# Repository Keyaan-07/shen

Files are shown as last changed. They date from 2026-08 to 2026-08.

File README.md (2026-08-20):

# SHEN
Shen is a low-cost pico-sized RP2350A development board along with the raspberry pi RM2, in a small 21mmx51mm form factor, with USB-C support. It is a 4 layer stackup with 1.0mm thickness.  

Check out the PCB online on [KiCanvas](https://kicanvas.org/?repo=https%3A%2F%2Fgithub.com%2FKeyaan-07%2Fshen%2Ftree%2Fmain%2Fhardware)

## Features
- WiFi and Bluetooth support
- dual-core
- 4MiB Flash storage(expandable upto 16MiB)
- User-LED
- High efficiency sychronous buck converter
- USB Boot
- Curvy Traces

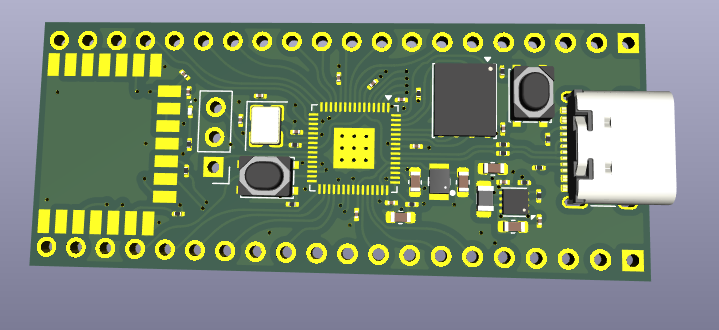
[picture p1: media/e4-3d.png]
3d render
  
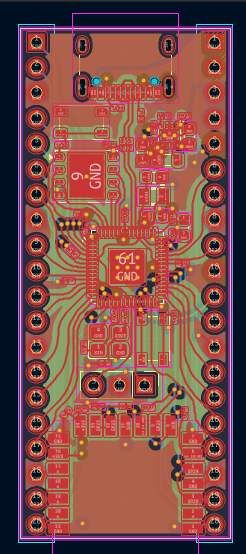
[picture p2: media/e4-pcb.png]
pcb

schematic

## BOM
Some parts(such as those in quantities of 50 and 100) are chosen because of the MOQ. 
|Designator |Function |Value |Footprint |Quantity|Price |Amount|Link |
|---|---|---|---|---|---|---|---|
|PCB |PCB | |21x51 |5+1 |2.1+3.07 |5.17  |https://jlcpcb.com/ |
|C1, C2, C4 |Capacitor |4.7u |603 |50 |0.0048 |0.24  |https://robu.in/product/tcc0603x5r475m160ct-cctc-smt-ceramic-capacitors-0603-x5r-475m4-7%c2%b5f%c2%b120-rated-voltage16v-thickness0-80mm-tape/ |
|C10, C11, C12, C13, C14, C18, C20, C5, C6, C7, C8, C9|Capacitor |100n |201 |100 |0.0011 |0.11  |https://robu.in/product/cl03a104ko3nnnc-samsang-16v-100nf-x5r-%c2%b110-0201-multilayer-ceramic-capacitors-mlcc-smd-smt-rohs/ |
|C15, C16 |Capacitor |22p |201 |50 |0.004 |0.2 |https://robu.in/product/grm0335c1h220ja01d-murata-cap-ceramic-22pf-50v-c0g-5-pad-smd-0201-125c-automotive-t-r/ |
|C17, C19 |Capacitor |10u |603 |4 |0.03 |0.12  |https://www.lcsc.com/product-detail/C7393892.html |
|D1 |LED |LED |402 |4 |0.01 |0.04  |https://www.lcsc.com/product-detail/C7496805.html |
|J4 |USB-C |USB_C_Receptacle_USB2.0_16P|USB_C_Receptacle_XKB_U262-16XN-4BVC11 |2 |0.06 |0.12  |https://www.lcsc.com/product-detail/C393939.html |
|L1 |Inductor |3.3u |IND-SMD_L2.0-W1.6_AOTA-B201610S3R3-101-T|2 |0.28 |0.56  |https://www.lcsc.com/product-detail/C42411119.html |
|L2 |Inductor |1u |805 |5 |0.13 |0.65  |https://robu.in/product/mlp2012h1r0mt0s1-tdk-1-1a-1uh-%c2%b120-120m%cf%89-0805-inductors-smd-rohs/ |
|R1, R2 |Resistor |27 |201 |50 |0.0038 |0.19  |https://robu.in/product/rc0201fr-0727rl-yageo-smd-chip-resistor-27-ohm-%C2%B1-1-50-mw-0201-0603-metric-thick-film-general-purpose/ |
|R9 |Resistor |63.4k |201 |100 |0.0011 |0.11  |https://robu.in/product/rc0201fr-0763k4l-yageo-50mw-thick-film-resistors-25v-%c2%b11-%c2%b1200ppm-%e2%84%83-63-4k%cf%89-0201-chip-resistor-surface-mount-rohs/ |
|R11 |Resistor |470 |201 |50 |0.0038 |0.19  |https://robu.in/product/0201wmj0471tee-uniohm-royal-ohm-50mw-thick-film-resistors-25v-%c2%b15-%c2%b1200ppm-%e2%84%83-470%cf%89-0201-chip-resistor-surface-mount-rohs/|
|R10, R12 |Resistor |10k |201 |50 |0.0038 |0.19  |https://robu.in/product/0201wmf1002tee-uniohm-royal-ohm-50mw-thick-film-resistors-25v-%c2%b11-%c2%b1200ppm-%e2%84%83-10k%cf%89-0201-chip-resistor-surface-mount-rohs/|
|R13, R14 |Resistor |5.1k |201 |50 |0.0038 |0.19  |https://robu.in/product/0201wmf5101tee-uniohm-royal-ohm-50mw-thick-film-resistors-25v%c2%b11%c2%b1200ppm-%e2%84%83-5-1k%cf%89-0201-chip-resistor-surface-mount-rohs/ |
|R3, R5, R6, R7, R8 |Resistor |1K |201 |50 |0.0038 |0.19  |https://robu.in/product/0201wmf1001tee-uniohm-royal-ohm-50mw-thick-film-resistors-25v%c2%b11%c2%b1200ppm-%e2%84%83-1k%cf%89-0201-chip-resistor-surface-mount-rohs/ |
|R4 |Resistor |33 |201 |50 |0.0038 |0.19  |https://robu.in/product/0201wmf330jtee-uniohm-royal-ohm-50mw-thick-film-resistors-25v%c2%b11%c2%b1200ppm-%e2%84%83-33%cf%89-0201-chip-resistor-surface-mount-rohs/ |
|SW1, SW2 |Switch |SW_Push |SW_SPST_PTS810 |5 |0.27 |1.35  |https://robu.in/product/pts810sjm250smtrlfs-ck-3-2mm-2-5mm-round-button-50ma-standing-paste-4-2mm-spst-160gf-16v-smd-tactile-switches-rohs/ |
|U1 |MCU |RP2350A |QFN-60-1EP_7x7mm_P0.4mm_EP3.4x3.4mm |3 |1.14 |3.42  |https://robu.in/product/raspberry-pi-rp2350a-microcontroller-ic/ |
|U2 |Flash Storage|W25Q32JVZP |WSON-8-1EP_6x5mm_P1.27mm_EP3.4x4.3mm |2 |0.96 |1.92  |https://robu.in/product/w25q32jwzpiq-tr-winbond-elec-32mbit-spi-133mhz-wson-8-ep5x6-nor-flash-rohs/ |
|U3 |RF module |RPI-RM2 |RPI_RM2 |2 |6.99 |13.98 |https://robu.in/product/raspberry-pi-radio-module-rmc20452t/ |
|U4 |Buck |TLV62084DSGx |WSON-8-1EP_2x2mm_P0.5mm_EP0.9x1.6mm |3 |0.31 |0.93  |https://robu.in/product/1-month-warranty-565/ |
|Y1 |Crystal |12MHz |Crystal_SMD_3225-4Pin_3.2x2.5mm |5 |0.19 |0.95  |https://robu.in/product/ysx321sl-12mhz-10pf-10ppm-4pins-smd-smt-metal-surface-quartz-crystal-pack-of-2/ |
| | | | | | | | |
| | | | | |Subtotal |31.01 | |
| | | | | |PCB Shipping|12 | |
| | | | | |Total Cost  |43.01 | |

## Name
Shen is taken from the chinese letter '参' which primarily means "to participate," "to join," "to take part in,"

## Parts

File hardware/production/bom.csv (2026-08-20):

Designator | Footprint | Quantity | Value | LCSC Part #
C1, C2, C4 | 0603 | 3 | 4.7u
C10, C11, C12, C13, C14, C18, C20, C5, C6, C7, C8, C9 | 0201 | 12 | 100n
C15, C16 | 0201 | 2 | 22p
C17, C19 | 0603 | 2 | 10u
D1 | 0402 | 1 | LED
J1, J2 | PinSocket_1x20_P2.54mm_Vertical | 2 | Conn_01x20_Pin
J3 | PinHeader_1x03_P2.54mm_Vertical | 1 | Conn_01x03_Pin
J4 | USB_C_Receptacle_XKB_U262-16XN-4BVC11 | 1 | USB_C_Receptacle_USB2.0_16P
L1 | IND-SMD_L2.0-W1.6_AOTA-B201610S3R3-101-T | 1 | 3.3u
L2 | 0805 | 1 | 1u
R1, R2 | 0201 | 2 | 27
R10, R12 | 0201 | 2 | 10k
R11 | 0201 | 1 | 470
R13, R14 | 0201 | 2 | 5.1k
R3, R5, R6, R7, R8 | 0201 | 5 | 1K
R4 | 0201 | 1 | 33
R9 | 0201 | 1 | 63.4k
SW1, SW2 | SW_SPST_PTS810 | 2 | SW_Push
U1 | QFN-60-1EP_7x7mm_P0.4mm_EP3.4x3.4mm | 1 | RP2350A
U2 | WSON-8-1EP_6x5mm_P1.27mm_EP3.4x4.3mm | 1 | W25Q32JVZP
U3 | RPI_RM2 | 1 | RPI-RM2
U4 | WSON-8-1EP_2x2mm_P0.5mm_EP0.9x1.6mm | 1 | TLV62084DSGx
Y1 | Crystal_SMD_3225-4Pin_3.2x2.5mm | 1 | 12MHz

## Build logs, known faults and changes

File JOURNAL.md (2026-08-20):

---
title: "Shen"
github: "https://github.com/Keyaan-07/shen"
description: "A pico-sized RP2350A devboard with wireless capabilities!"
created_at: "2026-08-20"
---

# entry 1(20 august)
I did a lot of work in the schematic, and i am almost done with everything, just adding a buck converter and the wireless chip is left! I have no space for the GPIO 24, but i think i'll use it up in bringing up the wireless chip!  
I forgot the image, here is the image:  
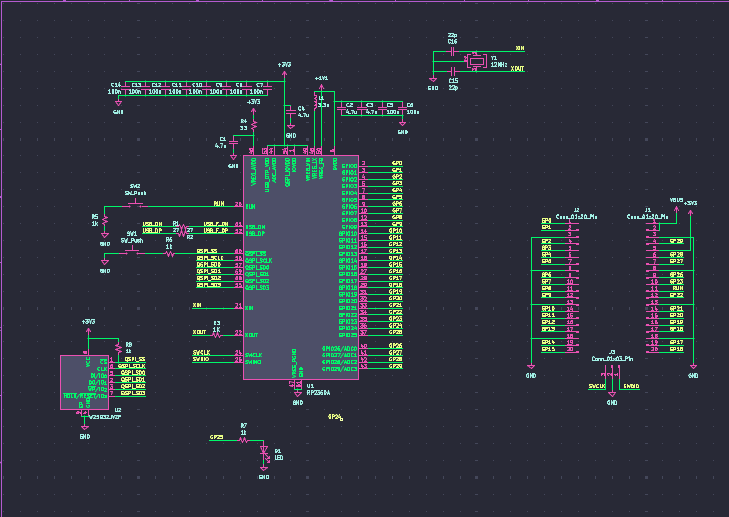
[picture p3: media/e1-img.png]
  

### Time spent: 1 hour 20 mins(1.3 hours)

# entry 2(20 august)
I completed the schematic, and i dont really understand how does the radio module 2 have 1 pin controlling 3 pins via resistors, but yeah it's nice. Also, here is what the schematic look like rn:  
shen
A lot of my footprints are 0201, basically all resistors and most capacitors. I will change them up if i cannot find proper 0201 parts!

### Time Spent: 1 hour

# entry 3(20 august)

I speedran the PCB, and most of the things are done, i am thinking of doing 4 layers instead of 2, so i might need to re-route it, the PCB dimensions are 21x51, thus i think it'll be made in $2 only, not $7 by JLC!
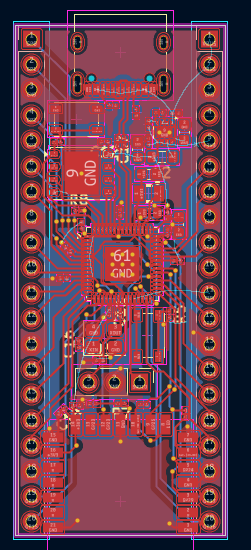
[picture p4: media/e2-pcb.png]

That is it for the session, i spent not too much time routing it!

### Time spent: 1 hour 45 mins(1.75 hours)

# entry 4(20 august)
Finally done with the PCB, and also, I had to do lots of stuff, first of all, there was this small ground pin number 8 for the ground pin of the flash, i had to change the bottom traces just to fit a via!  
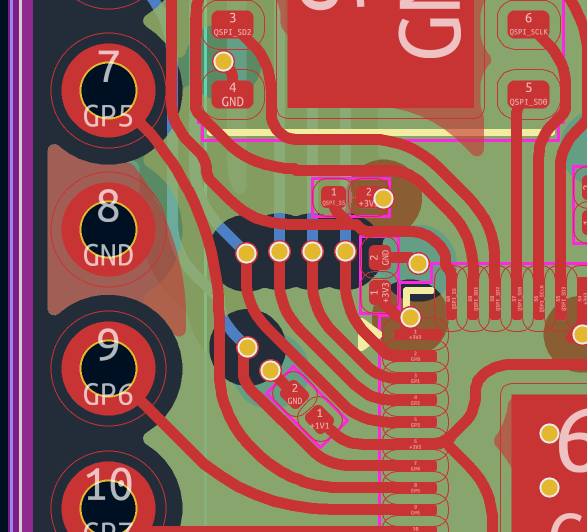
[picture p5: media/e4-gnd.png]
e4-gnd
  
this is what the completed PCB render looks like in Kicad:  
3d render  
pcb
schematic

### Time Spent: 1 hour

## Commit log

2026-08-20 part of schematic done
    [shen.kicad_pcb, shen.kicad_sch]
2026-08-20 made the schematic
2026-08-20 schematic complete
    [shen.kicad_pcb, shen.kicad_sch]
2026-08-20 pcb work
    [shen.kicad_pcb, shen.kicad_sch]
2026-08-20 PCB complete
    [shen.kicad_pcb, shen.kicad_sch]
2026-08-20 added production files
    [bom.csv, designators.csv, positions.csv]
2026-08-20 shrunk LED size
    [bom.csv, positions.csv, shen.kicad_pcb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]
2026-08-20 added 3d file
    [shen.kicad_pcb]
2026-08-20 added BOM
    [bom.csv]
2026-08-20 added bom and name origin
